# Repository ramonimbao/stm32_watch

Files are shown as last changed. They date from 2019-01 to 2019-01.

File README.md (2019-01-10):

# DIY STM32-based Watch

This repository contains the necessary files for building your own STM32-based watch.

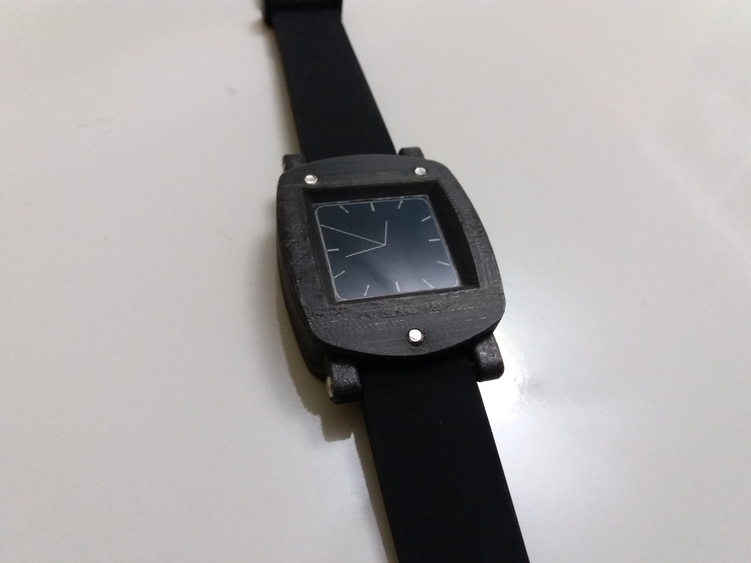
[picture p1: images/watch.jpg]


# Prerequisites

- [OpenOCD](https://gnu-mcu-eclipse.github.io/openocd/install/)
- [System Workbend for STM32](http://www.st.com/en/development-tools/sw4stm32.html)

# Assembly instructions

Details assembly instructions for the project are located in [BUILDING.md](BUILDING.md).

# License

This project is licensed under the MIT license - see the [LICENSE.md](LICENSE.md) for more details.

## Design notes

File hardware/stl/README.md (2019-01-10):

# Printing Settings

- 0.025 mm layer height
- 100% infill
- Supports enabled for [`back_face.stl`](back_face.stl) and [`lcd_support.stl`](lcd_support.stl).

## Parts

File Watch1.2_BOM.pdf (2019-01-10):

Watch v1.2 - Bill of Materials
Part | Value | Package | Description | Qty | Distributor | Order Number
C1,C5,C6,C7,C8, C12,C13,C14 | 100n | 0805 | CAP 100n, 0805 | 8 | MOUSER | 80-C0805C104K9R
C2,C3,C9 | 1u | 0805 | CAP 1u, 0805 | 3 | MOUSER | 603-CC0805KR5BB105
C4 | 4.7u | 0805 | CAP 4.7u, 0805 | 1 | MOUSER | 77-VJ0805G475KXYTBC
C10,C11 | 10p | 0805 | CAP, 10p, 0805 | 2 | MOUSER | 710-885012007010
D1 | LED | 0805 | LED, any, 0805 | 1 | MOUSER | 604-APT2012SGC
L1 | 1k | 0805 | FERRITE, 1k, 0805 | 1 | MOUSER | 963-BK2125HS102-T
P1 | | FPC-10-0.5 | 10-pin, 0.5mm-pitch FPC connector | 1 | MOUSER | 538-505110-1092
PB1,PB2,PB3 | | 4.46x3.5x3.3 | Tact switch | 3 | MOUSER | 688-SKRTLA
R1,R2,R3,R4 | 10k | 0805 | R, 10k, 0805 | 4 | MOUSER | 588-AS08J1002ET
R6 | 510 | 0805 | R, 510, 0805 | 1 | MOUSER | 71-CRCW0805510RJNEA
SB1,SB2,SB3 | 0 | 0805 | R, 0, 0805 | 3 | MOUSER | 667-ERJ-6GEY0R00V
U1 | STM32L051K8T6 | LQFP-32 | STM32L0 MCU | 1 | MOUSER | 511-STM32L051K8T6
U2 | | | Keystone 3003 | 1 | MOUSER | 534-3003
X1 | 32.768kHz | 3.2x1.5 | 3.2x1.5 32.768kHz 10ppm 7pF | 1 | MOUSER | 815-S07AIG-32.76871T
| LS013B7DH03 | | 1.28” Sharp Memory LCD | 1 | MOUSER | 852-LS013B7DH03

MISC PARTS
QTY
3 | M3x12 countersunk screws
2 | M3x8 countersunk screws
4 | M2x12 pan head screws
1 | 20mm watch strap
| 3D printed parts

## https://github.com/ramonimbao/stm32_watch/

blob/master/BUILDING.md (https://github.com/ramonimbao/stm32_watch/blob/master/BUILDING.md)

PART | DETAILED ASSEMBLY INSTRUCTIONS

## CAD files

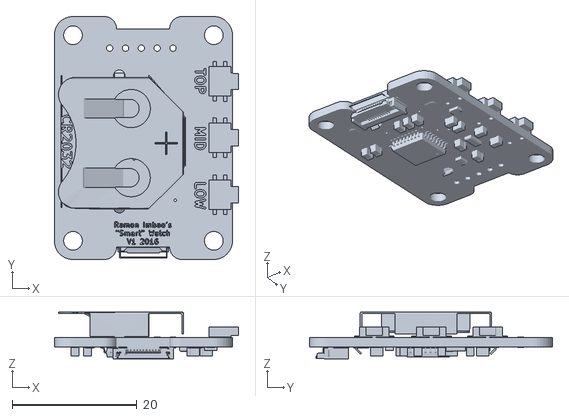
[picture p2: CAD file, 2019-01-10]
hardware/board/Export/Watch.stl
29.6 x 39.0 x 7.53

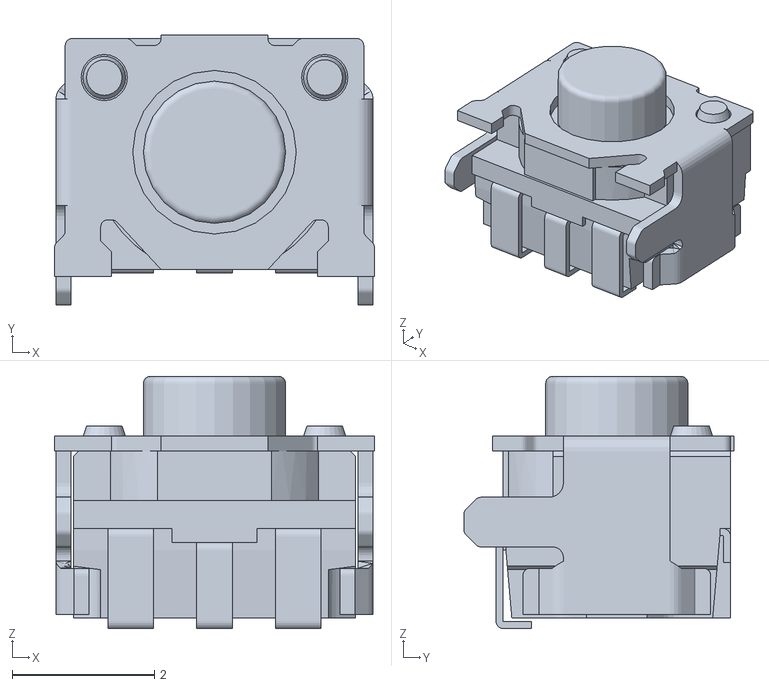
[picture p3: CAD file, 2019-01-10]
hardware/board/shapes3D/Tact_Switch_ALPS_SKRTLA.stl
4.50 x 3.80 x 3.55

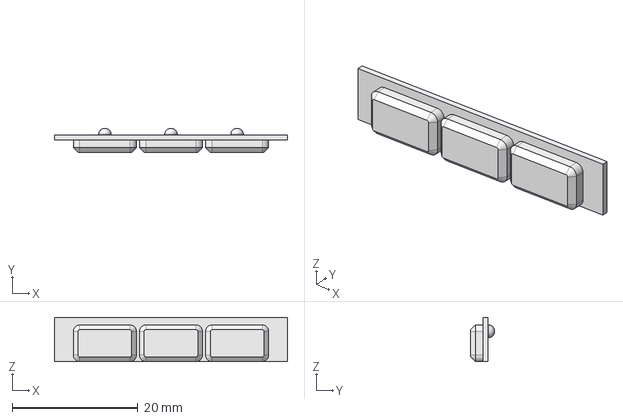
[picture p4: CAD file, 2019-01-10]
hardware/freecad/buttons_v2.fcstd
37.0 x 3.80 x 7.00 mm

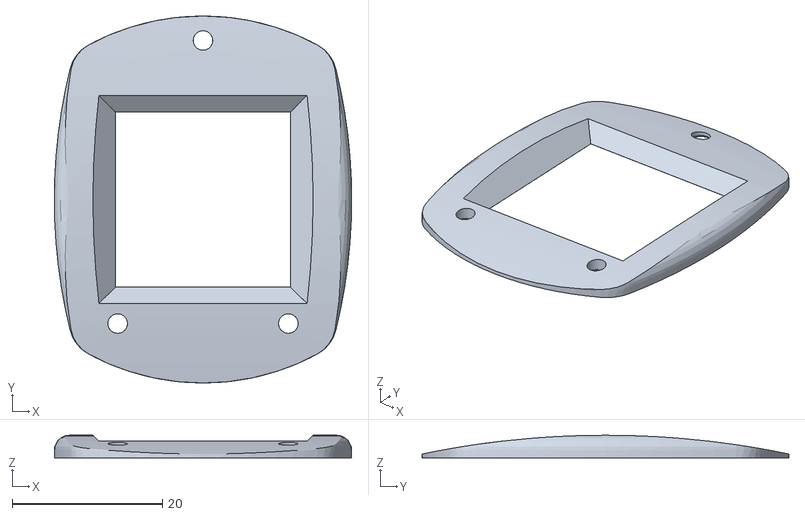
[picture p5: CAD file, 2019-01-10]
hardware/stl/watch_face.stl
39.6 x 48.8 x 3.00

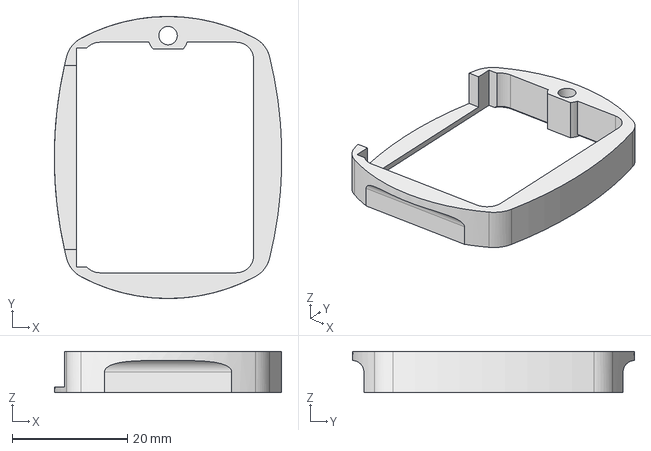
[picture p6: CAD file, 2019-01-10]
hardware/freecad/body_inner_v6.fcstd
39.5 x 48.9 x 7.20 mm

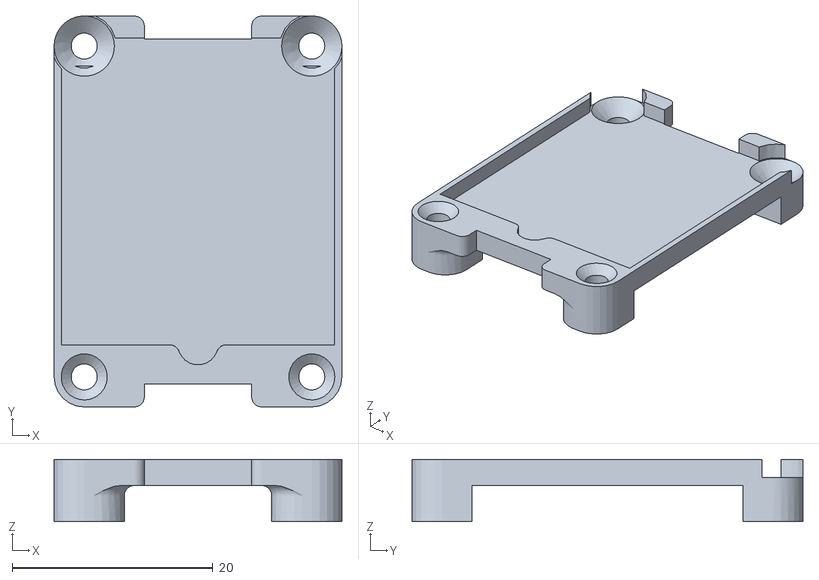
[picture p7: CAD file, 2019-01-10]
hardware/stl/lcd_support.stl
28.7 x 39.0 x 6.20

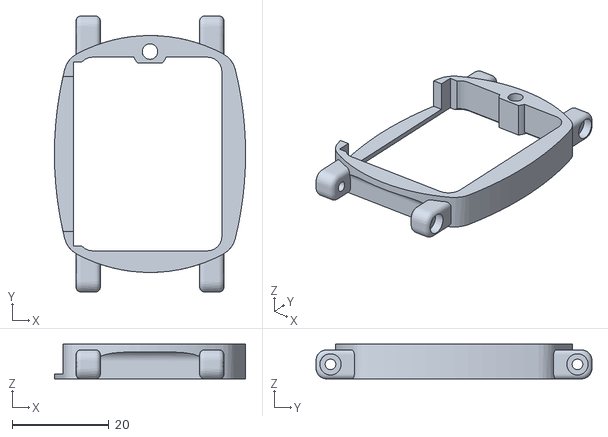
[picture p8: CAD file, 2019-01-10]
hardware/stl/body_inner.stl
39.5 x 57.0 x 7.20

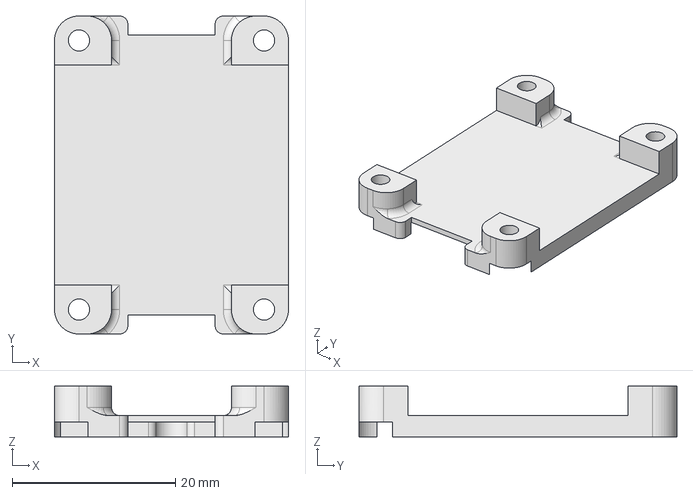
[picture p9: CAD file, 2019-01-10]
hardware/freecad/lcd_support_v4.fcstd
28.7 x 39.0 x 6.20 mm

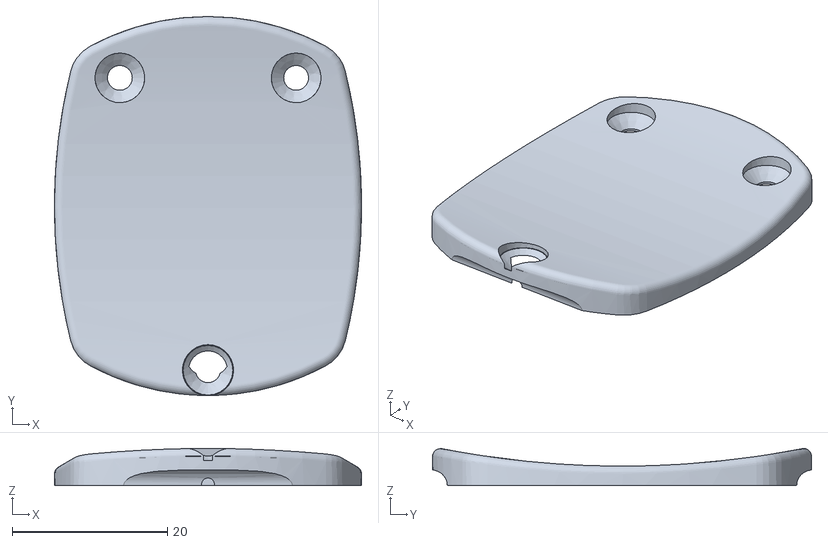
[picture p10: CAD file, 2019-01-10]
hardware/stl/back_face.stl
39.6 x 48.8 x 4.78

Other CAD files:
hardware/freecad/watch_face_v2.fcstd
hardware/stl/buttons.stl
hardware/board/Watch.stl

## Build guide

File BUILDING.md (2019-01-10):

# Assembly Instructions

Below, I detail how to properly assemble the watch from bare board to finished product.

## Tools used

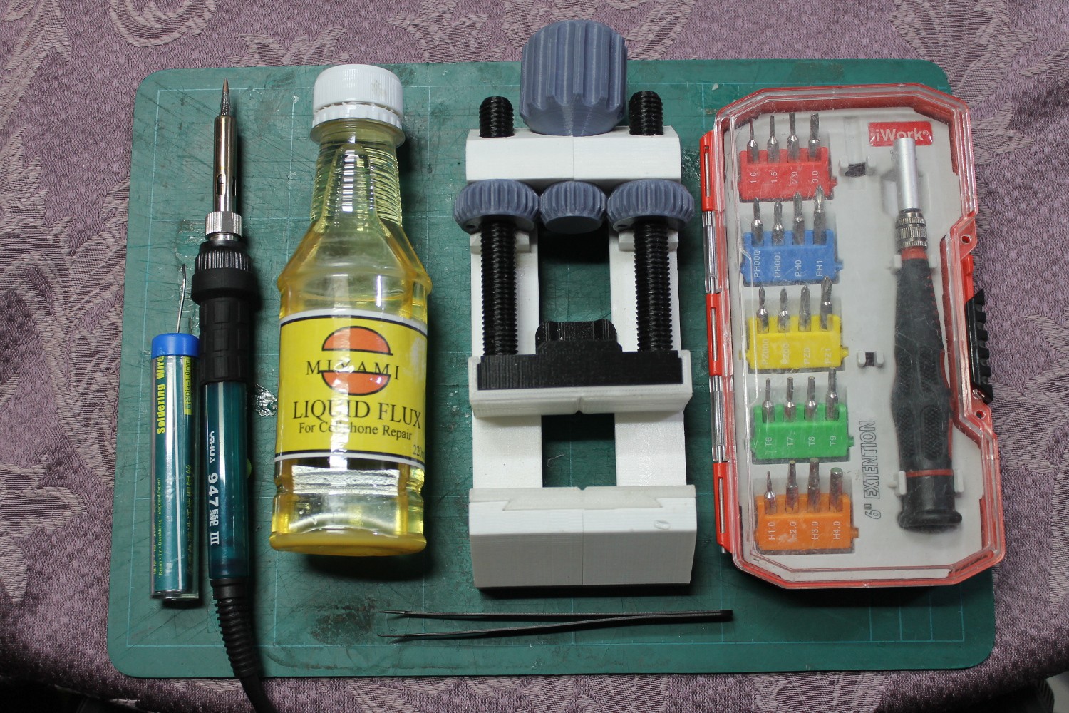
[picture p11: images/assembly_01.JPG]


- Soldering iron and lead (thinner is better)
- Liquid flux (pictured above is an el cheapo flux)
- SMD tweezers
- [PCB vise](https://www.thingiverse.com/thing:2064269) (since I don't own helping hands)
- Screwdriver set
- Solder wick (not pictured)

Have the bill of materials handy to easily identify which parts go where!

## Bare board

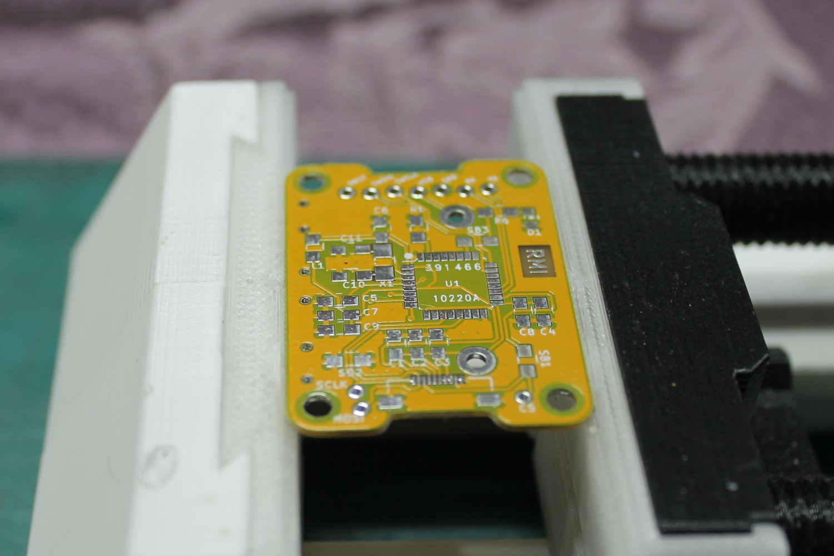
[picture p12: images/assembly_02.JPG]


Firstly, we'll work on the top part of the board. Specifically, the first thing I like soldering would be the FPC connector — it's the most difficult part to solder with a 0.5 mm pitch.

## FPC connector

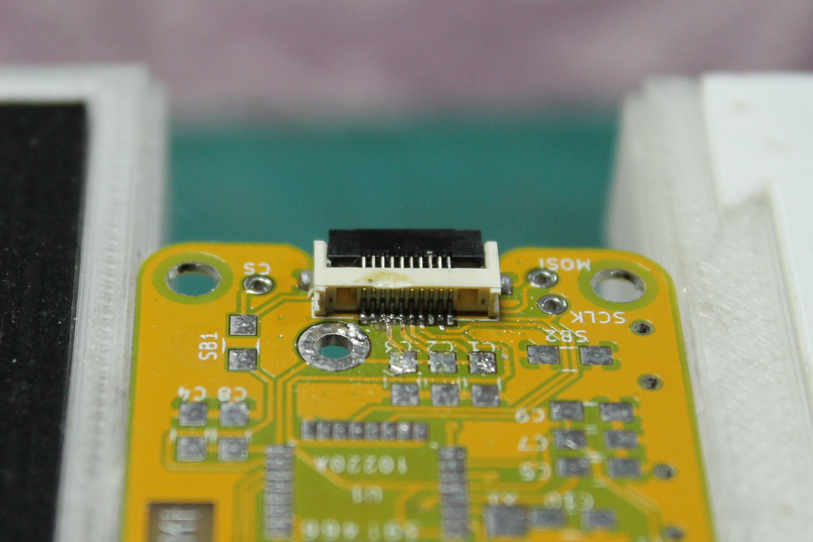
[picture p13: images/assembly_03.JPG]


Use plenty of flux and a solder wick to wick away any excess solder. Let's say pin 1 is the leftmost pin (though it's not). Don't worry about shorting pins 1 and 2, or pins 3, 4, 5, and 6. Those are GND and VBAT respectively. The rest of the pins must be isolated from each other however.

## Passives

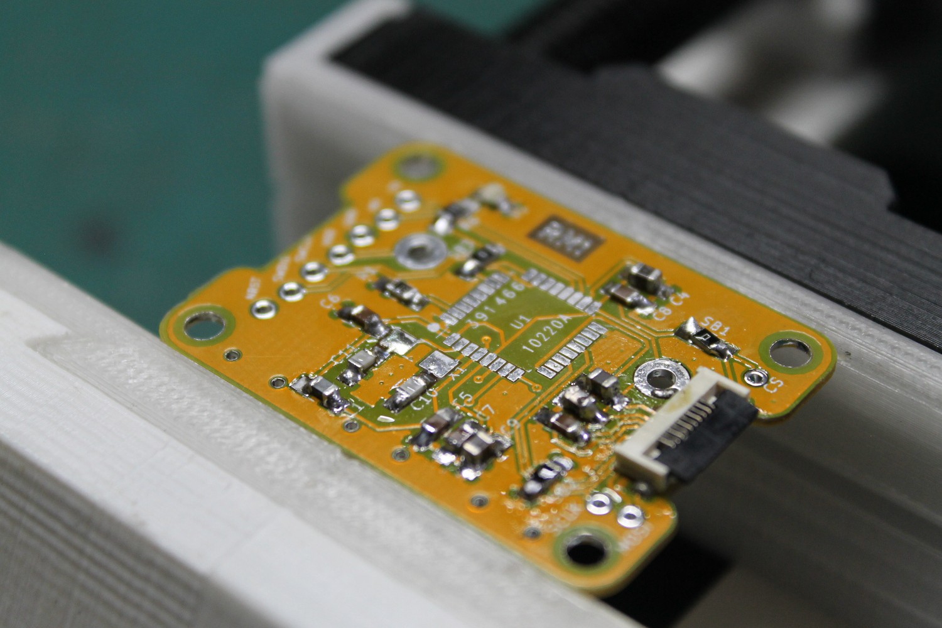
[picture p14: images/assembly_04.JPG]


Solder all the passives on the top part of the board. Just go through the bill of materials and take your time. Make sure to do a better job than I did as seen in the photo.

## Crystal

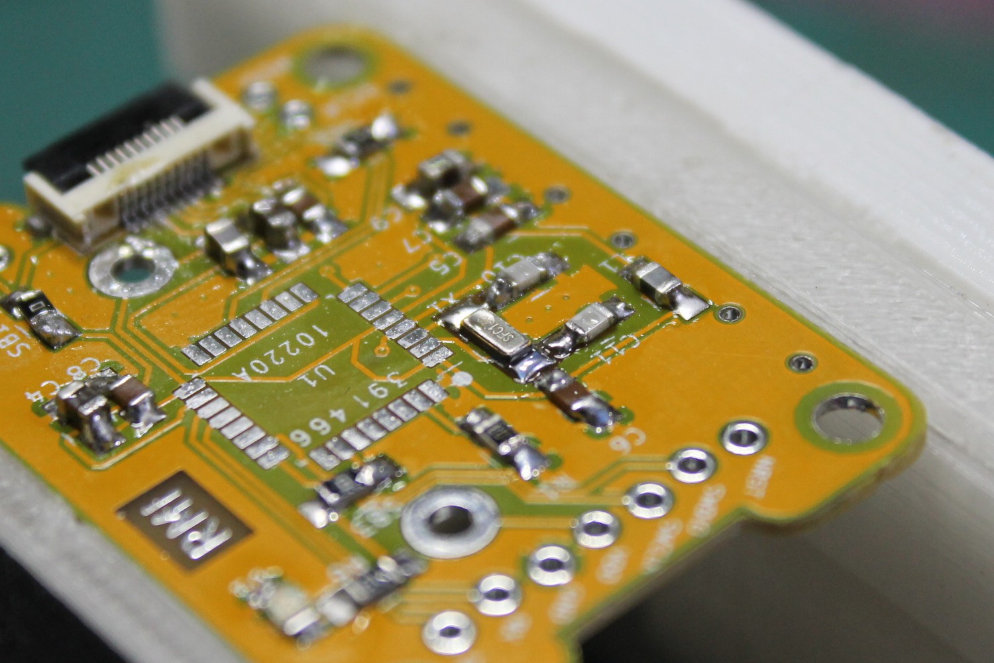
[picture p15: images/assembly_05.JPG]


I read somewhere that you shouldn't heat up the crystal too much or you'll damage it, so take care in soldering this.

## STM32 IC

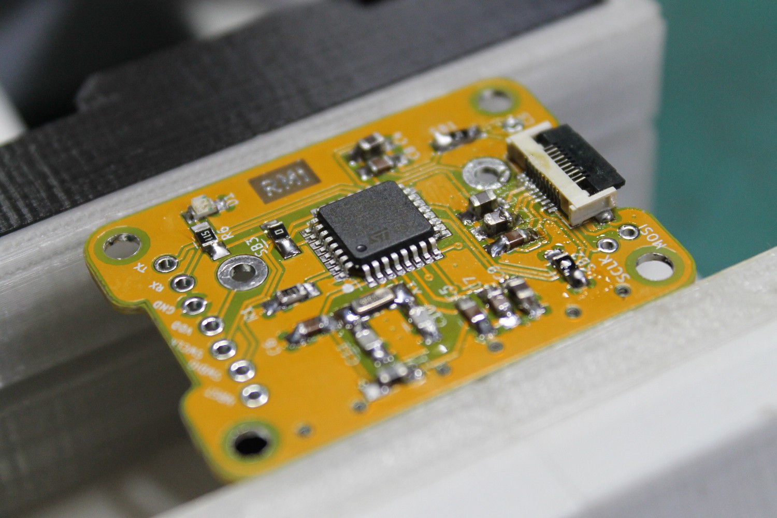
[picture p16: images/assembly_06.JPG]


Align the IC on all the pads. Make sure that the dot on the package matches the dot on the board indicated by the silkscreen.

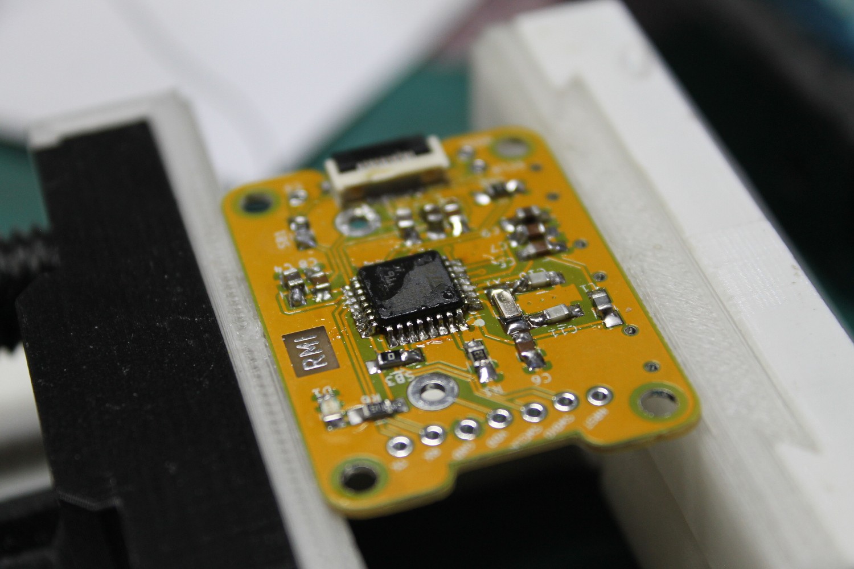
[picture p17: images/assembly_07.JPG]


Here it is all soldered up. As you can see, I was very liberal with the flux.

## Passives (back)

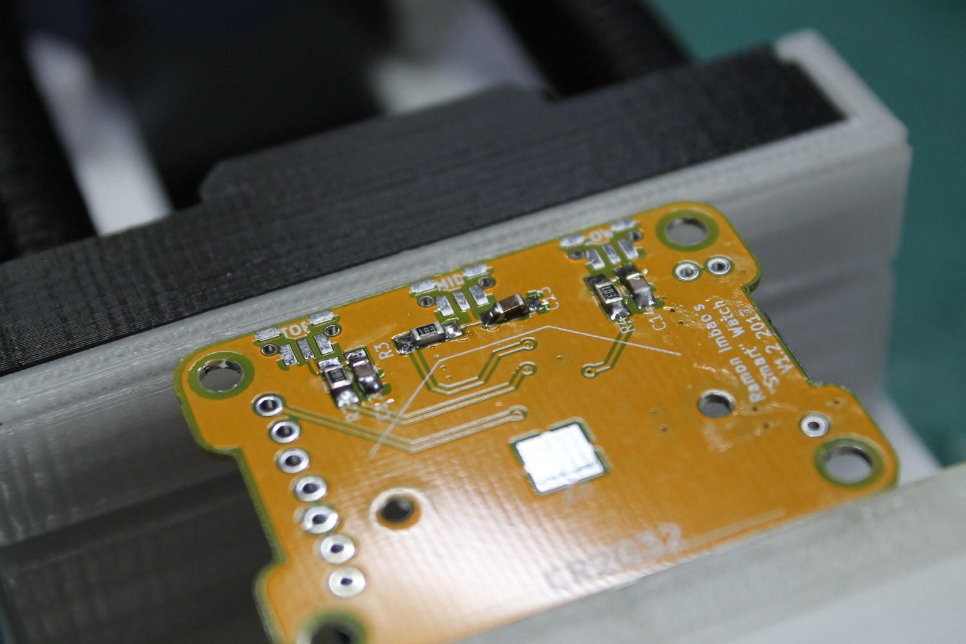
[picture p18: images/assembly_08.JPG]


Now you can flip the board and solder the rest of the passives at the back. All of these are just 100nF capacitors and 10kΩ resistors.

## Buttons

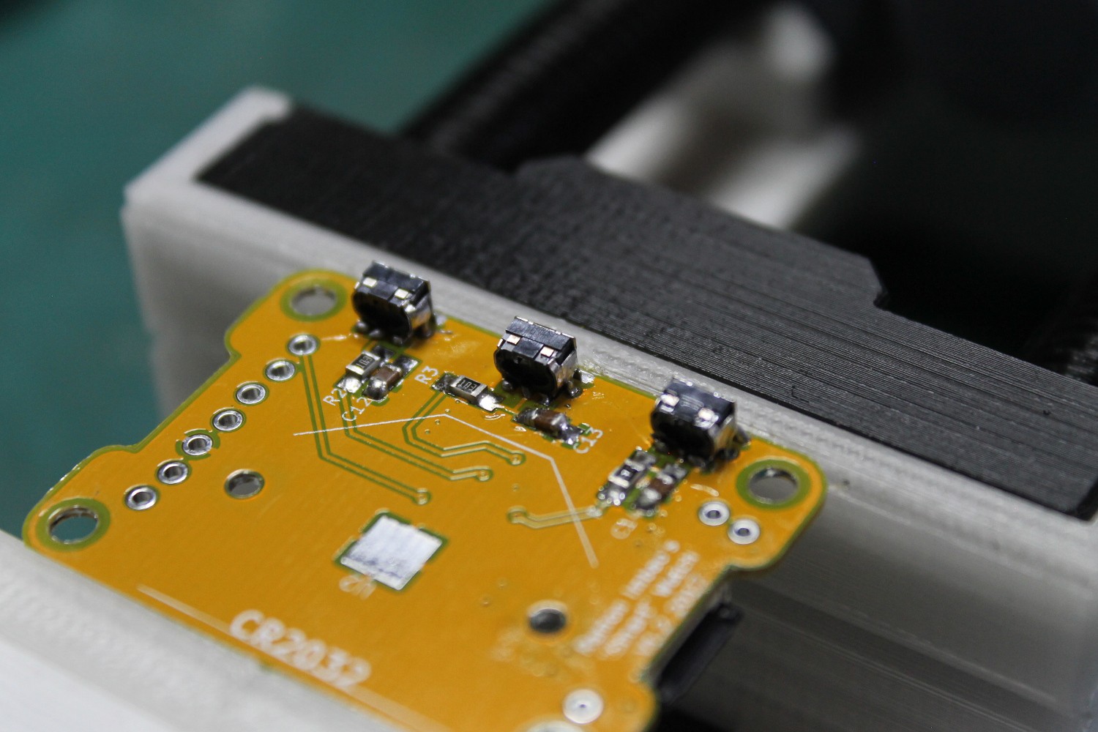
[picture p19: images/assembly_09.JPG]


Place the buttons and align them using the holes on the board. It's a bit more difficult to solder these since the leads don't extend outward. A hot air station might be better suited for this.

## Solder pad

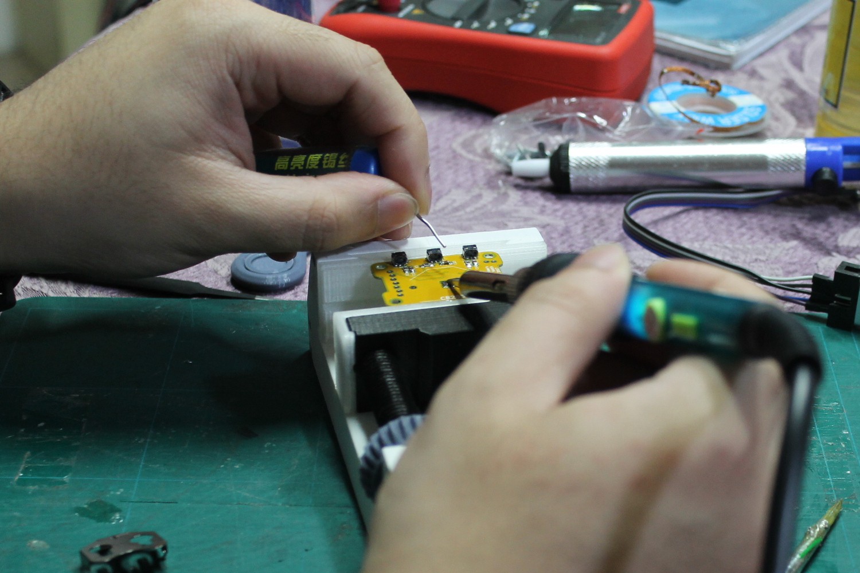
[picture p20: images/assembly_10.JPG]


Don't forget to add a *tiny* amount of solder to the big square pad you see. This helps create a tighter fit on the battery and ensures a good connection. This should create a small bump, around 1mm thick or less.

## Battery holder

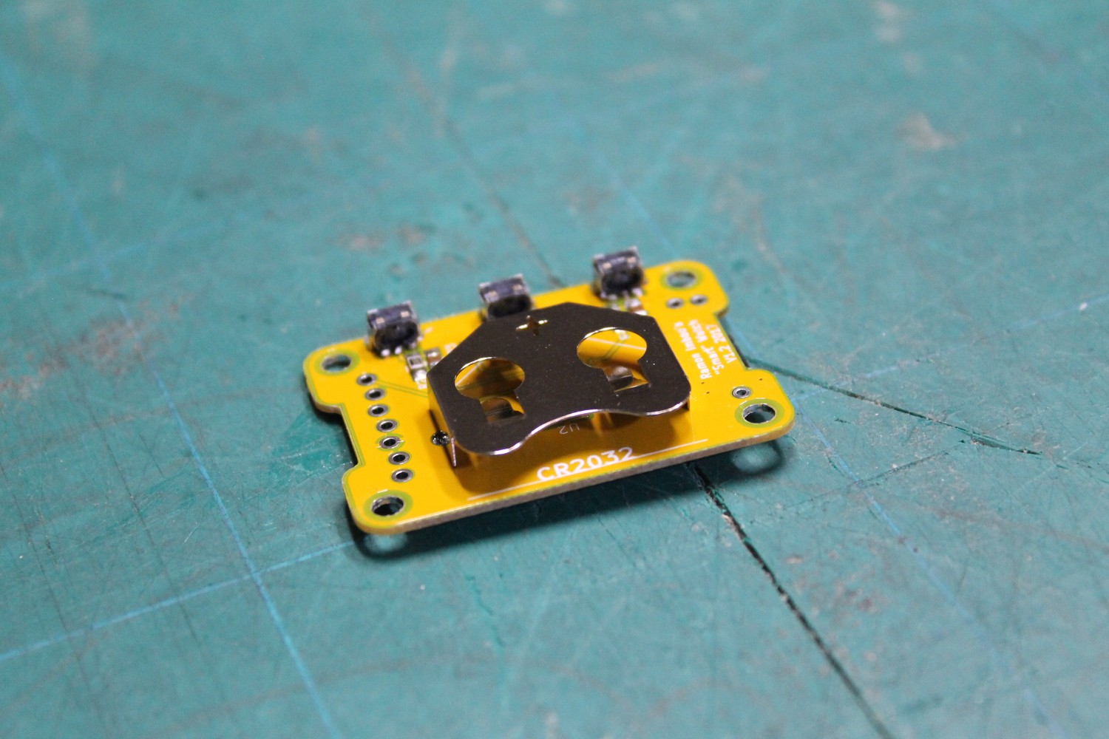
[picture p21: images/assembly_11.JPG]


Finally, solder the battery holder on. It's the only through-hole component of the build.

## Connect ST-Link

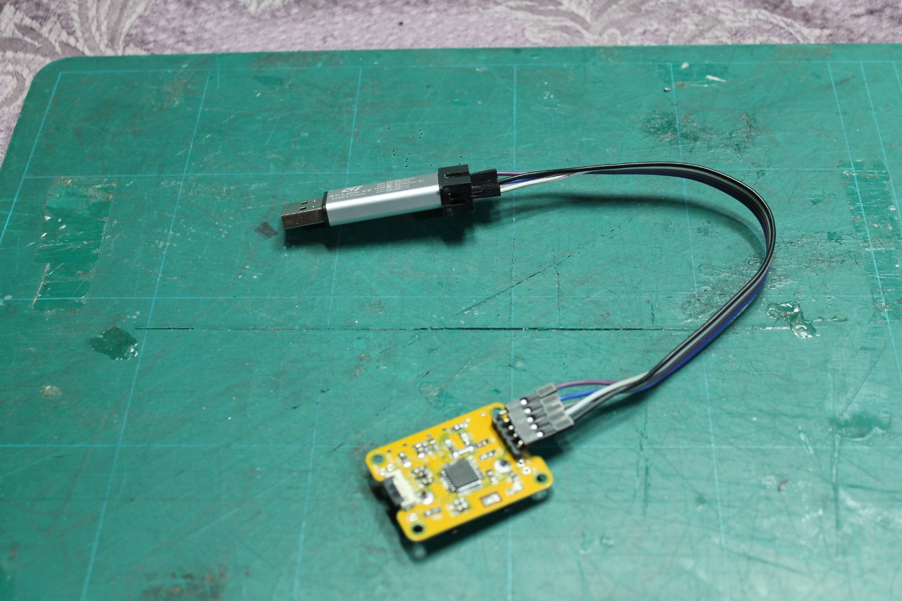
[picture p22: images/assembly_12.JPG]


I used a Chinese ST-Link clone. Simply connect the five relevant pins from the programmer to the board: `SWCLK`, `SWDIO`, `NRST`, `VCC`, and `GND`. There is no need to solder header pins to the board since it's staggered to ensure a tight fit.

## OpenOCD

Follow the necessary instructions for [installing OpenOCD on your system](https://gnu-mcu-eclipse.github.io/openocd/install/).

Open up a command line interface, and type in the following command to start up the OpenOCD debugger:

```
openocd -f interface/stlink-v2.cfg -f target/stm32l0.cfg
```

The output should be something like this:

```
Open On-Chip Debugger 0.10.0-dev-00399-g19df456 (2016-11-04-15:40)
Licensed under GNU GPL v2
For bug reports, read
	http://openocd.org/doc/doxygen/bugs.html
Info : auto-selecting first available session transport "hla_swd". To override use 'transport select <transport>'.
adapter speed: 300 kHz
adapter_nsrst_delay: 100
Info : The selected transport took over low-level target control. The results might differ compared to plain JTAG/SWD
none separate
Info : Unable to match requested speed 300 kHz, using 240 kHz
Info : Unable to match requested speed 300 kHz, using 240 kHz
Info : clock speed 240 kHz
Info : STLINK v2 JTAG v27 API v2 SWIM v6 VID 0x0483 PID 0x3748
Info : using stlink api v2
Info : Target voltage: 3.216787
Info : stm32l0.cpu: hardware has 4 breakpoints, 2 watchpoints
```

## Programming with SW4STM32

As my firmware files rely on [System Workbench for STM32 (SW4STM32)](http://www.st.com/en/development-tools/sw4stm32.html), a copy of that is needed to be installed.

Load up the project in SW4STM32, and flash to the board by pressing hitting Run.

## Connect the screen

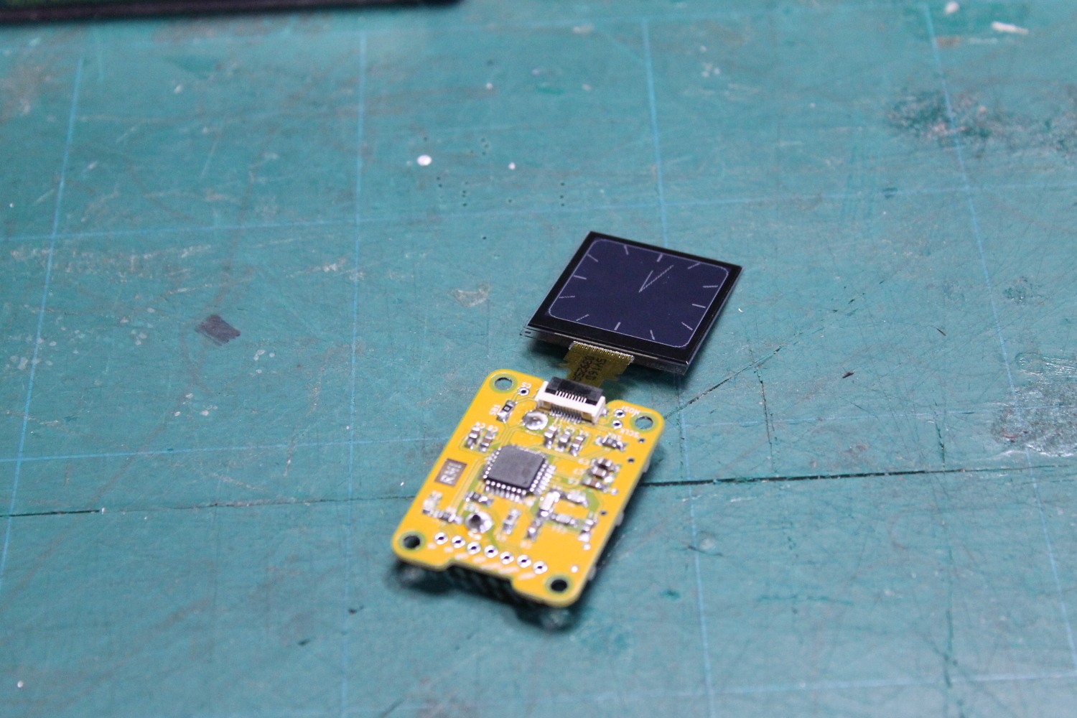
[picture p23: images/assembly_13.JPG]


Disconnect the programmer, connect a battery, and connect the screen via the 10-pin FPC connector. You should see the clock face on the display.

## Test buttons

The top and bottom buttons should move the minute hand forwards and backwards. The middle button should reset the second hand. The previous picture doesn't have a second hand, but a section of the code can be uncommented to have this appear.

## Attach screen support

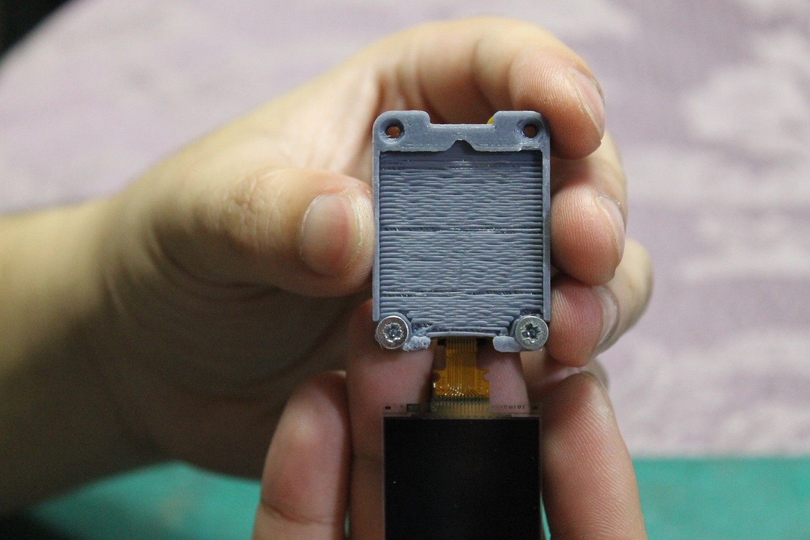
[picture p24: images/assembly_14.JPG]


It is **highly recommended** to pre-tap the holes on the screen support. You can use an M3 tap or just use a screw to create the threads.

Place the screen support on the board and partially screw in two M3×8 countersunk screws at the bottom. Take note of the orientation of the 3D printed part in relation to the screen.

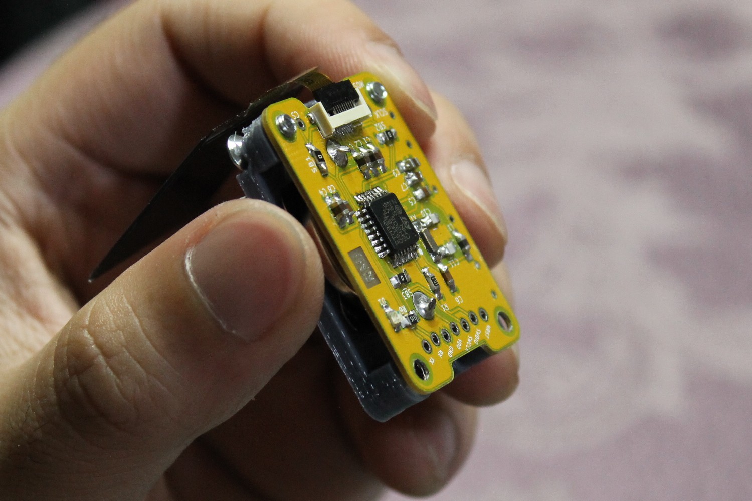
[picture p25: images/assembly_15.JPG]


The screws should stick out by around 2-3mm so you can use it to align it to the back piece.

## Back piece

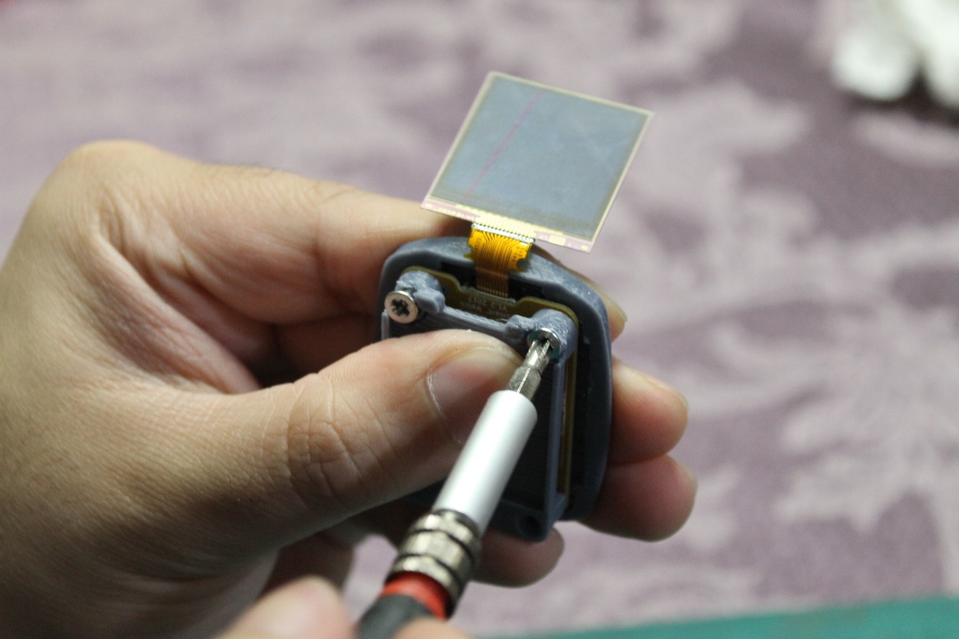
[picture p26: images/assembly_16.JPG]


Here the board and screen support is being screwed into the back piece. The threaded sections on the back piece are quite short so make sure you accidentally enlarge the hole. Tighten the screws until the top of them is flush with the screen support.

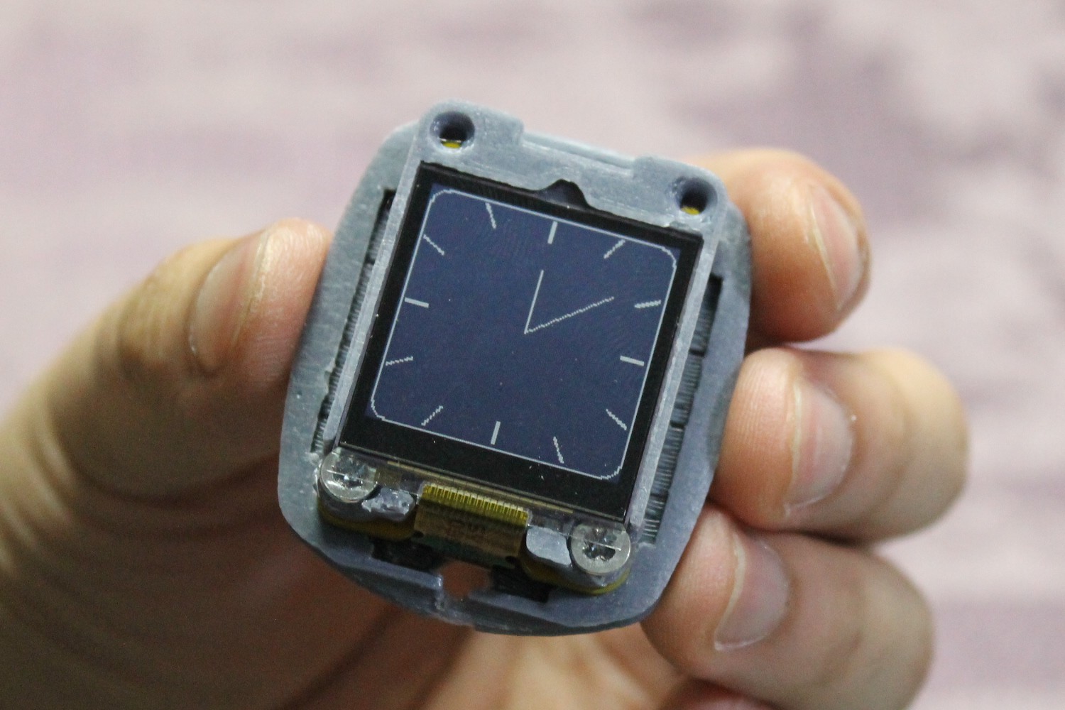
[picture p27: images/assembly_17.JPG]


The screen should be able to sit flush on the screen support. Be careful not to bend or shatter the LCD when inserting — these things are incredibly fragile!

## Middle piece and flexible buttons

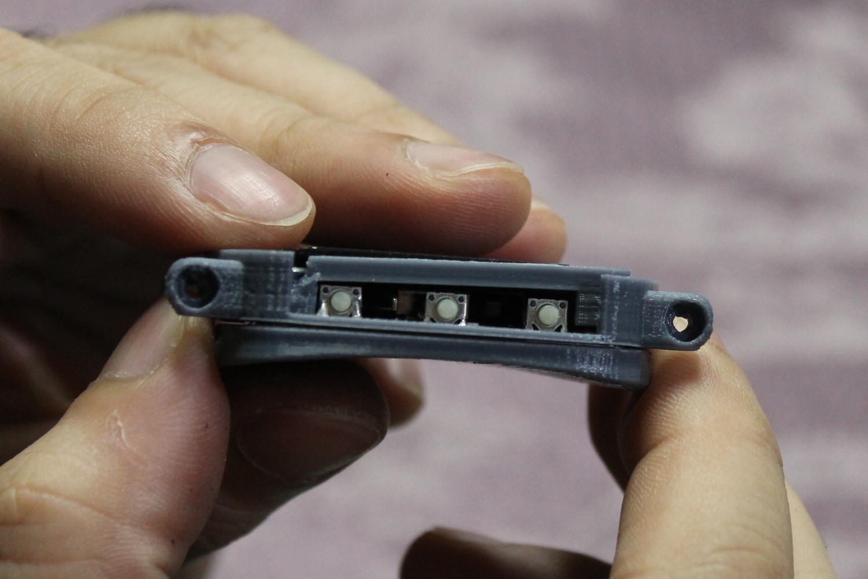
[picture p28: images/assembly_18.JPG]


Now you can insert the middle piece through the assembly. Take note that the cutout faces the side with the buttons, and that the thinner section is nearer to the bottom.

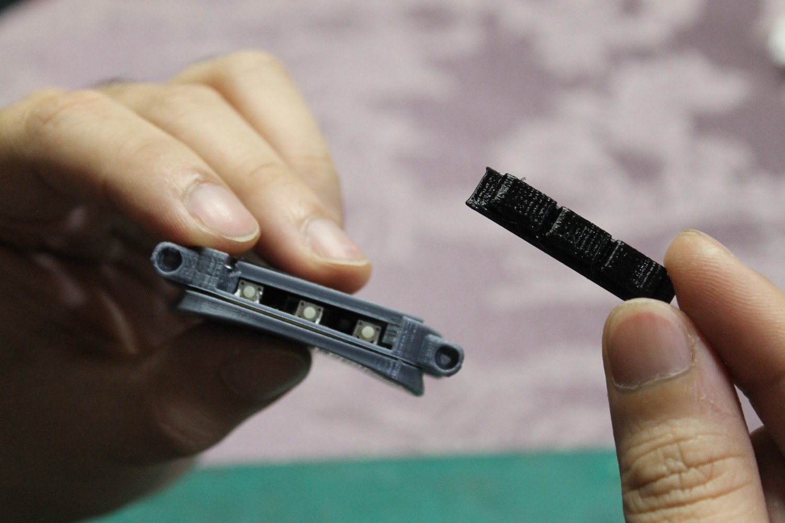
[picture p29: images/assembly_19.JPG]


Now place the flexible buttons inside. The buttons go flush side top.

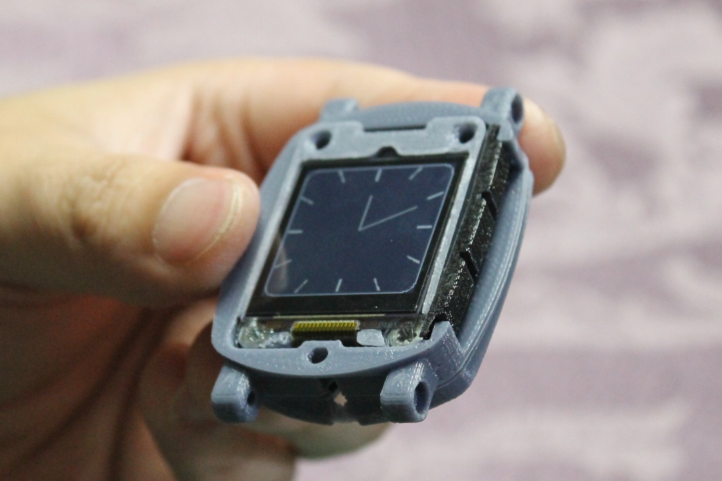
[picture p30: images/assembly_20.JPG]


## Fit cover and screw from back

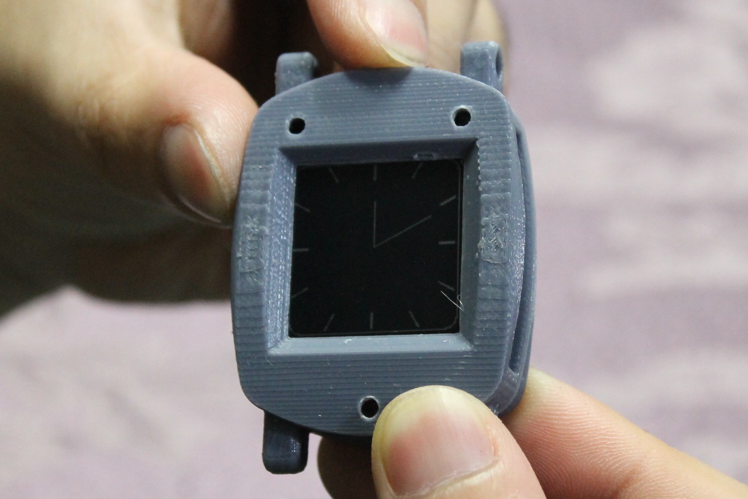
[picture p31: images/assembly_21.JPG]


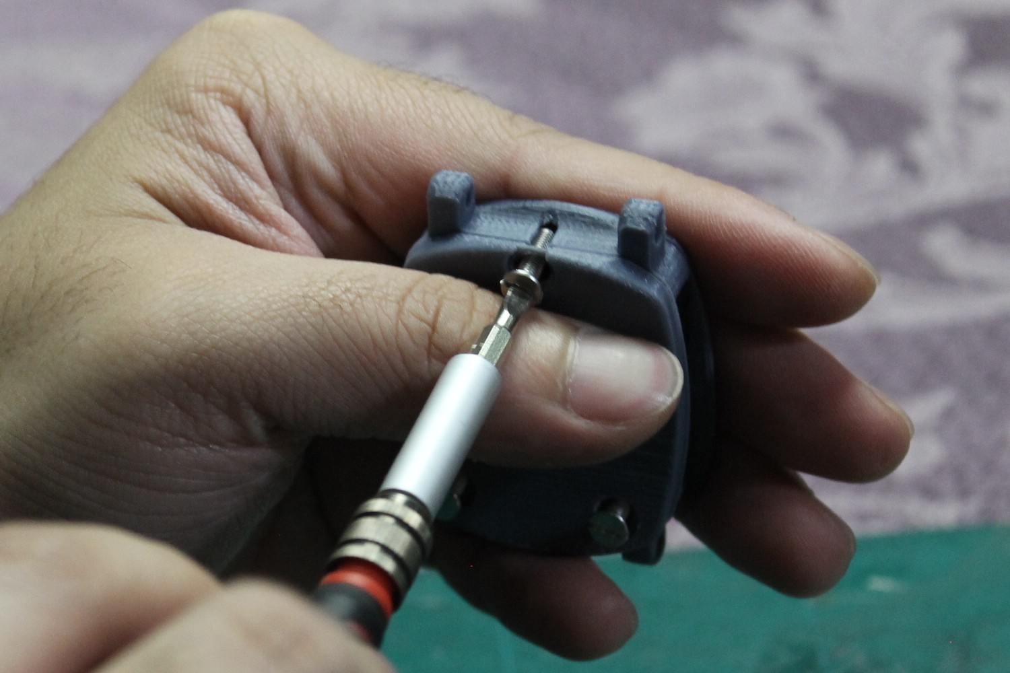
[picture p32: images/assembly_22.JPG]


Place the cover in front and insert the M3×12 countersunk screws from the back. This may be tight if you don't tap the threads of the screen support beforehand.

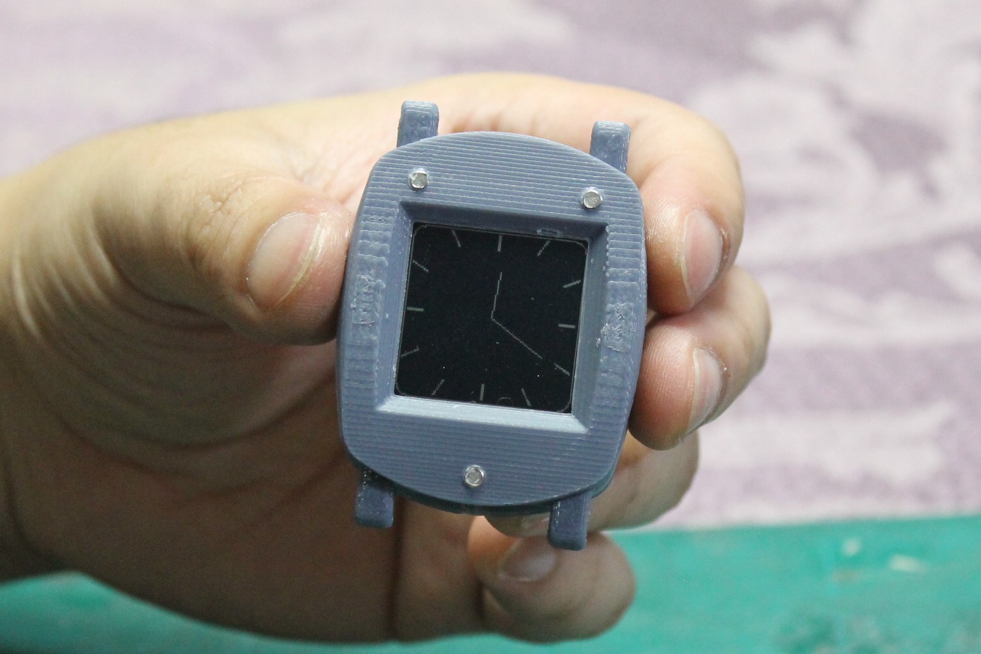
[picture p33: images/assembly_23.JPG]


Almost complete. Yes, the screws stick out somewhat, but it's not bothersome for me.

## Attach straps

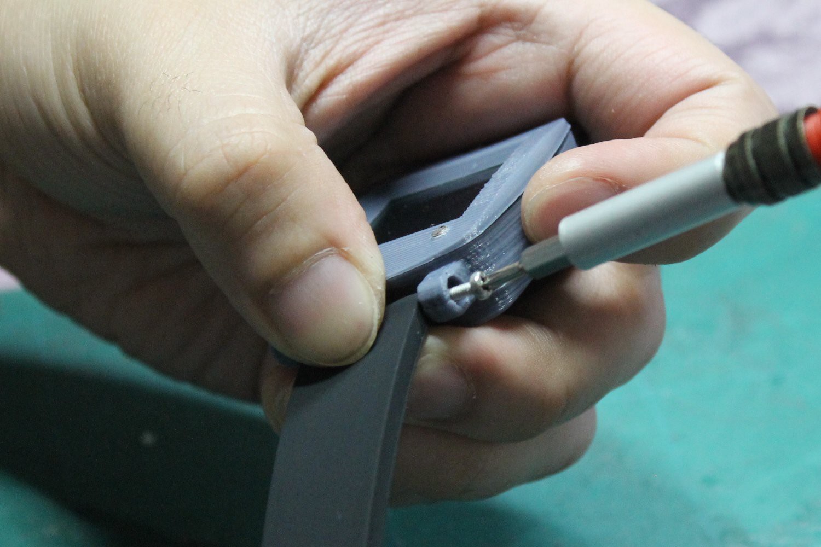
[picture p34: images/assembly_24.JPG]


Use the M2×12 cap head screws to attach the straps to the body. There are four in total.

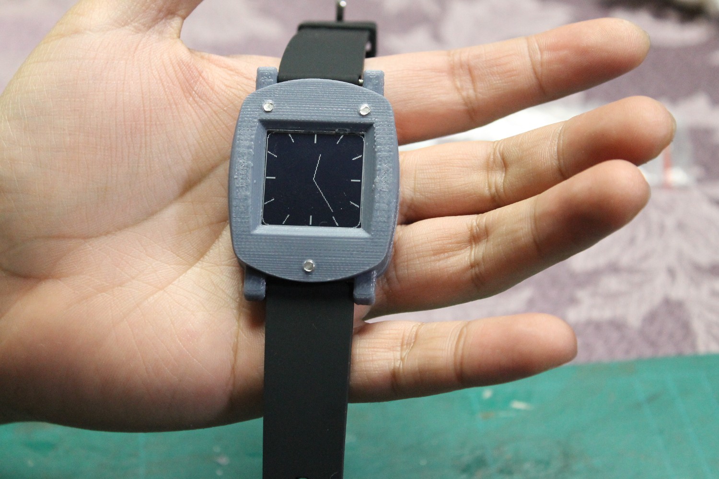
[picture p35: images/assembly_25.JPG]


**Complete!** Wear it with pride. Make more for your family and friends.

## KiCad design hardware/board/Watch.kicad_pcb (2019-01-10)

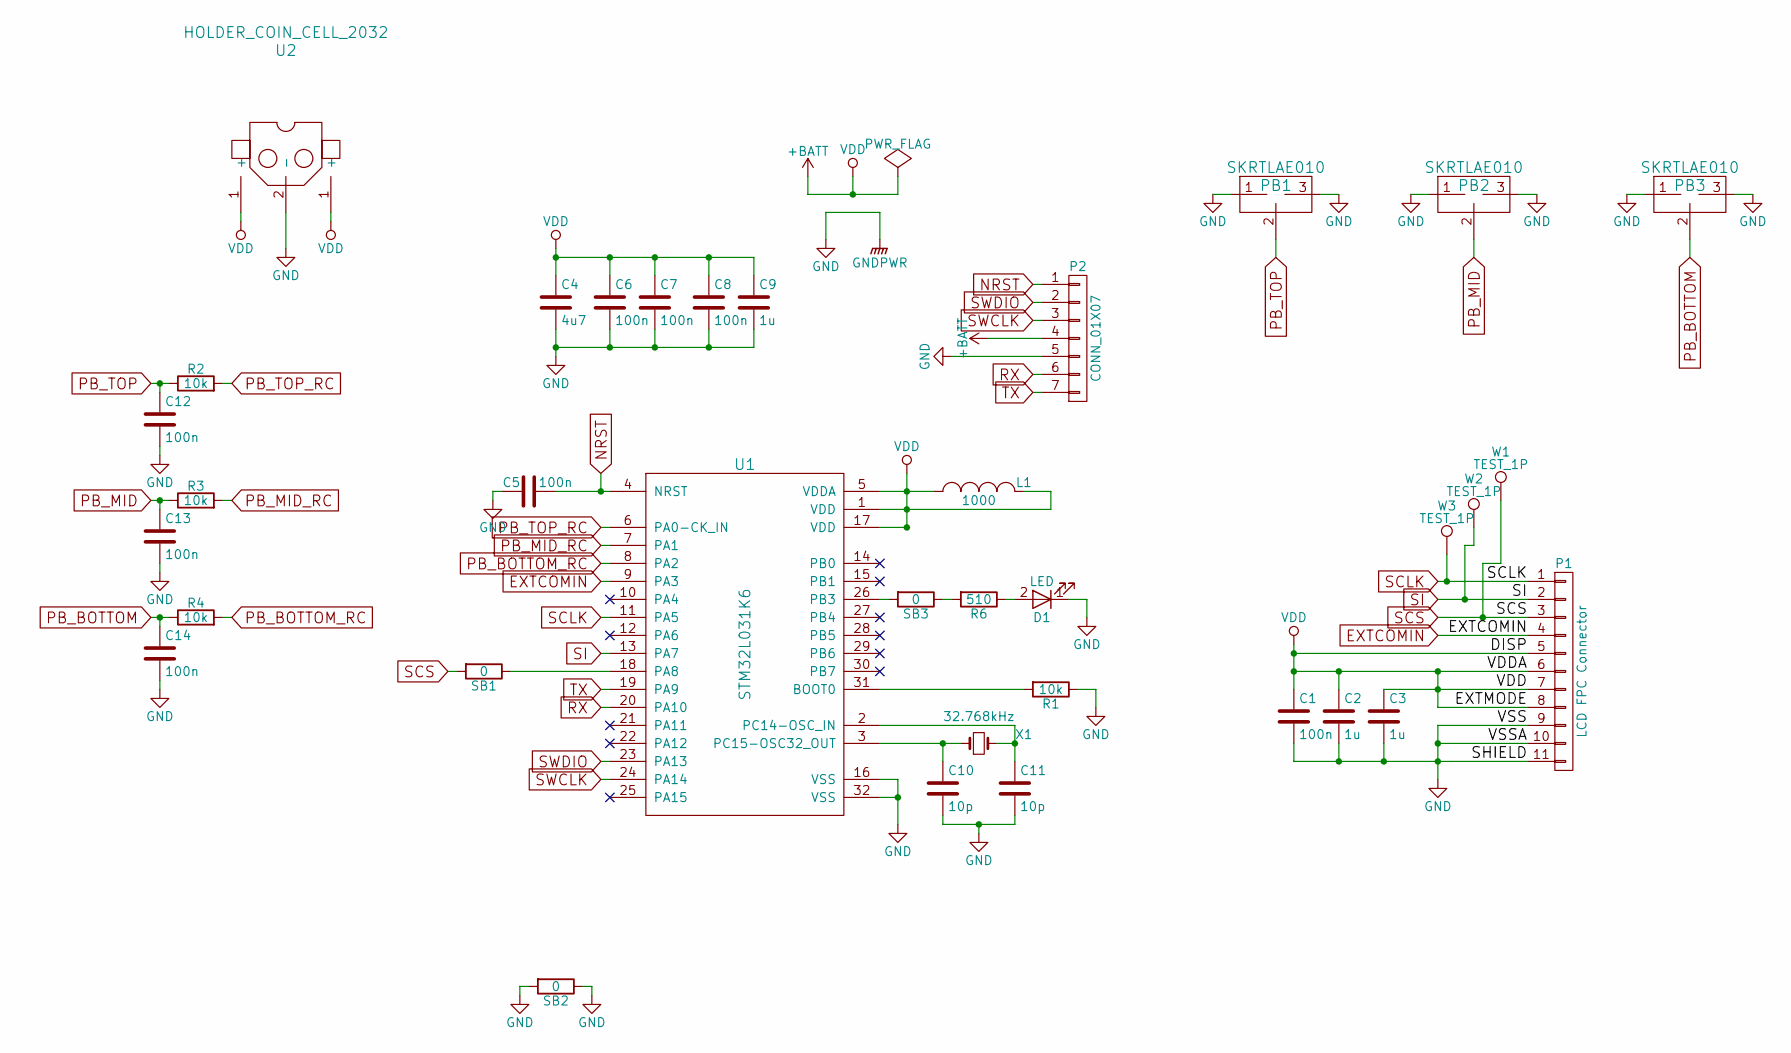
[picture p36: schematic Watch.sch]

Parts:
C1, C5, C6, C7, C8, C12, C13, C14: 100n; C_0805_HandSoldering
C2, C3, C9: 1u; C_0805_HandSoldering
C4: 4u7; C_0805_HandSoldering
C10, C11: 10p; C_0805_HandSoldering
D1: LED; LED_0805
L1: 1000; R_0805_HandSoldering
P1: LCD FPC Connector; FPC_10pin_0.5pitch
P2: CONN_01X07; Pin_Header_Straight_1x07_Pitch2.54mm
PB1, PB2, PB3: SKRTLAE010; SKTDLDE010
R1, R2, R3, R4: 10k; R_0805_HandSoldering
R6: 510; R_0805_HandSoldering
SB1, SB2, SB3: 0; R_0805_HandSoldering
U1: STM32L031K6; LQFP-32_7x7mm_Pitch0.8mm
U2: HOLDER_COIN_CELL_2032; HOLDER_COIN_CELL_2032_THROUGHHOLE
W1, W2, W3: TEST_1P; Measurement_Point_Round-TH_Small
X1: 32.768kHz; Crystal_3.2x1.5mm_HandSoldering

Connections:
+BATT: C1.1, C2.1, C3.1, C4.1, C6.1, C7.1, C8.1, C9.1, L1.1, L1.2, P1.5, P1.6, P1.7, P1.8, P2.4, U1.1 (VDD), U1.5 (VDDA), U1.17 (VDD), U2.1 (+)
EXTCOMIN: P1.4, U1.9 (PA3)
GND: C1.2, C2.2, C3.2, C4.2, C5.2, C6.2, C7.2, C8.2, C9.2, C10.2, C11.2, C12.2, C13.2, C14.2, D1.1 (K), P1.9, P1.10, P1.11, P2.5, PB1.1, PB1.3, PB2.1, PB2.3, PB3.1, PB3.3, R1.1, SB2.1, SB2.2, U1.16 (VSS), U1.32 (VSS), U2.2 (-)
NRST: C5.1, P2.1, U1.4 (NRST)
unnamed: C10.1, U1.3 (PC15-OSC32_OUT), X1.1
unnamed: C11.1, U1.2 (PC14-OSC_IN), X1.2
unnamed: D1.2 (A), R6.1
unnamed: R1.2, U1.31 (BOOT0)
unnamed: R6.2, SB3.1
unnamed: SB1.1, U1.18 (PA8)
unnamed: SB3.2, U1.26 (PB3)
PB_BOTTOM: C14.1, PB3.2, R4.1
PB_BOTTOM_RC: R4.2, U1.8 (PA2)
PB_MID: C13.1, PB2.2, R3.1
PB_MID_RC: R3.2, U1.7 (PA1)
PB_TOP: C12.1, PB1.2, R2.1
PB_TOP_RC: R2.2, U1.6 (PA0-CK_IN)
RX: P2.6, U1.20 (PA10)
SCLK: P1.1, U1.11 (PA5), W3.1
SCS: P1.3, SB1.2, W1.1
SI: P1.2, U1.13 (PA7), W2.1
SWCLK: P2.3, U1.24 (PA14)
SWDIO: P2.2, U1.23 (PA13)
TX: P2.7, U1.19 (PA9)

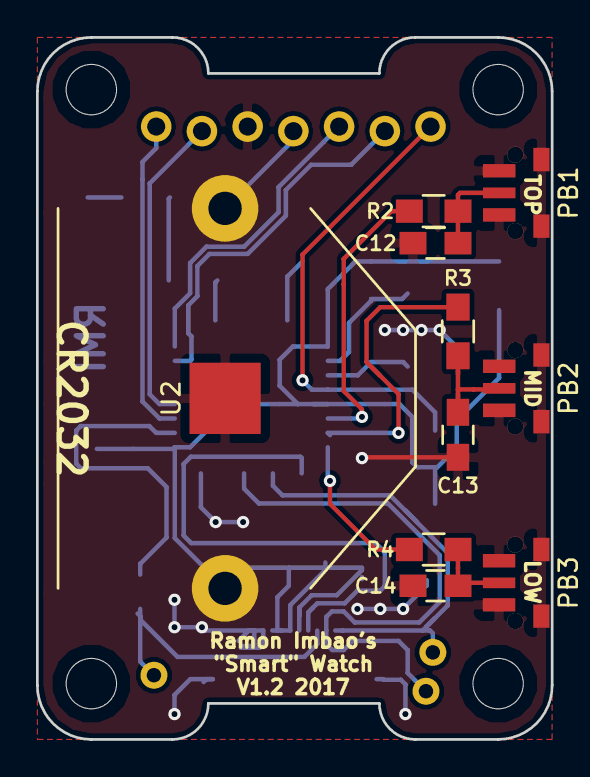
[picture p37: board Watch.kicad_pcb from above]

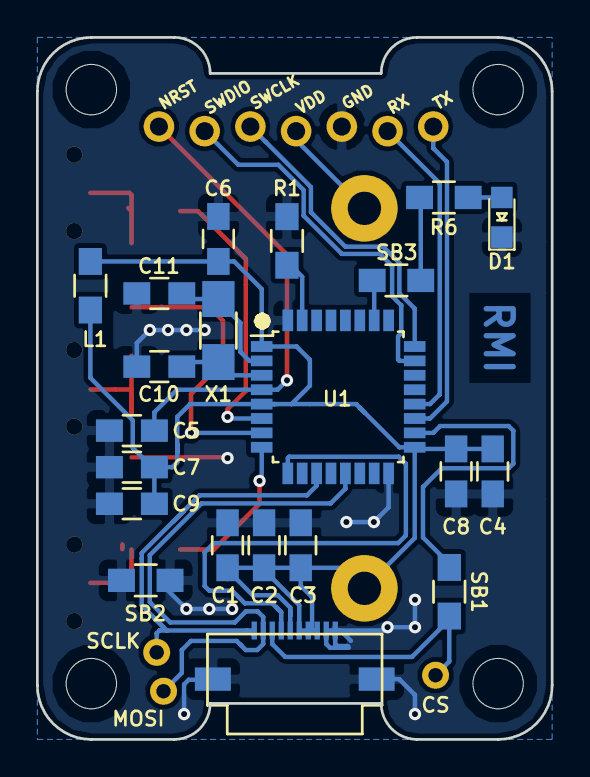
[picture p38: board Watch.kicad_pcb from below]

Board: 2 copper layers, 28.6 x 39.0 mm, 35 parts (25 on the bottom side), 24 nets.

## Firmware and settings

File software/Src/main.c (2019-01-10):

/**
  ******************************************************************************
  * File Name          : main.c
  * Description        : Main program body
  ******************************************************************************
  *
  * Copyright (c) 2017 STMicroelectronics International N.V. 
  * All rights reserved.
  *
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
  ******************************************************************************
  */
/* Includes ------------------------------------------------------------------*/
#include "main.h"
#include "stm32l0xx_hal.h"
#include "cmsis_os.h"

/* USER CODE BEGIN Includes */
#include "inittriglut.h"
#include <stdlib.h>
/* USER CODE END Includes */

RTC_HandleTypeDef hrtc;

SPI_HandleTypeDef hspi1;
DMA_HandleTypeDef hdma_spi1_tx;

osThreadId defaultTaskHandle;

/* USER CODE BEGIN PV */
#define SCREEN_WIDTH	128
#define SCREEN_HEIGHT	128

volatile uint8_t data[SCREEN_HEIGHT * ((SCREEN_WIDTH >> 3) + 2)];
const uint8_t command[1] = {0x03};
const uint8_t clear_cmd[2] = {0x05, 0x00};

RTC_TimeTypeDef sTimeStamp;
RTC_DateTypeDef sDateStamp;
HAL_RTCStateTypeDef currentState;

uint8_t hours = 12, minutes = 01, seconds = 30;

typedef enum {
	false = 0U,
	true = 1U
} bool;

typedef void (*drawFuncDef)(uint8_t, uint8_t);
/* USER CODE END PV */

void SystemClock_Config(void);
void Error_Handler(void);
static void MX_GPIO_Init(void);
static void MX_DMA_Init(void);
static void MX_SPI1_Init(void);
static void MX_RTC_Init(void);
void StartDefaultTask(void const * argument);

/* USER CODE BEGIN PFP */

/* USER CODE END PFP */

/* USER CODE BEGIN 0 */
static void setPixel(uint8_t x, uint8_t y) {
	if (x > 127 || y > 127) return;
	/*x %= 128;
	y %= 128;*/
	data[(y*((SCREEN_WIDTH>>3)+2))+(x>>3)+1] &= ~(1 << (x % 8));
}

static void clearPixel(uint8_t x, uint8_t y) {
	if (x > 127 || y > 127) return;
	/*x %= 128;
	y %= 128;*/
	data[(y*((SCREEN_WIDTH>>3)+2))+(x>>3)+1] |= (1 << (x % 8));
}

void clearDisplay() {
	for(uint8_t dy=0; dy<SCREEN_HEIGHT; dy++) {
		for(uint8_t dx=0; dx<SCREEN_WIDTH; dx++) {
			setPixel(dx,dy);
		}
	}
}

static drawFuncDef otherFunction(const drawFuncDef func) {
	if (func == setPixel) return clearPixel;
	else return setPixel;
}

static void drawCircle(uint8_t x0, uint8_t y0, uint8_t radius, const drawFuncDef drawFunc) {
	int x = radius;
	int y = 0;
	int err = 0;
	while (x >= y) {
		drawFunc(x0 + x, y0 + y);
		drawFunc(x0 + y, y0 + x);
		drawFunc(x0 - y, y0 + x);
		drawFunc(x0 - x, y0 + y);
		drawFunc(x0 - x, y0 - y);
		drawFunc(x0 - y, y0 - x);
		drawFunc(x0 + y, y0 - x);
		drawFunc(x0 + x, y0 - y);

		y += 1;
		err += 1 + (y << 2);
		if (((err-x) << 2) + 1 > 0) {
			x -= 1;
			err += 1 - (x << 2);
		}
	}
}

// source: https://rosettacode.org/wiki/Bitmap/Bresenham%27s_line_algorithm#C
static void drawLine(uint8_t x0, uint8_t y0, uint8_t x1, uint8_t y1, const drawFuncDef drawFunc) {
	int dx = abs(x1-x0), sx = x0 < x1 ? 1 : -1;
	int dy = abs(y1-y0), sy = y0 < y1 ? 1 : -1;
	int err = (dx > dy ? dx : -dy)/2, e2;

	for (;;) {
		drawFunc(x0,y0);
		if (x0==x1 && y0==y1) break;
		e2 = err;
		if (e2 > -dx)	{ err -= dy; x0 += sx; }
		if (e2 < dy)	{ err += dx; y0 += sy; }
	}
}

static void drawRect(uint8_t x1, uint8_t y1, uint8_t w, uint8_t h, const drawFuncDef drawFunc) {
	drawLine(x1,y1,x1+w,y1,drawFunc);
	drawLine(x1,y1,x1,y1+h,drawFunc);
	drawLine(x1,y1+h,x1+w,y1+h,drawFunc);
	drawLine(x1+w,y1,x1+w,y1+h,drawFunc);
}

static void drawArc(uint8_t x0, uint8_t y0, uint8_t radius, int16_t start, int16_t end, const drawFuncDef drawFunc) {
	for(int16_t theta=start+1; theta<end; theta++) {
		int32_t _x1 = x0 + radius * i16_cos(theta-1) / 32768;
		int32_t _y1 = y0 + radius * i16_sin(theta-1) / 32768;
		int32_t _x2 = x0 + radius * i16_cos(theta) / 32768;
		int32_t _y2 = y0 + radius * i16_sin(theta) / 32768;
		//drawFunc((uint8_t)_x, (uint8_t)_y);
		drawLine(_x1, _y1, _x2, _y2, drawFunc);
	}
}

static void drawRoundedRect(uint8_t x1, uint8_t y1, uint8_t w, uint8_t h, uint8_t r, const drawFuncDef drawFunc) {
	drawLine(x1+r,y1,x1+w-r,y1,drawFunc);
	drawLine(x1,y1+r,x1,y1+h-r,drawFunc);
	drawLine(x1+r,y1+h,x1+w-r,y1+h,drawFunc);
	drawLine(x1+w,y1+r,x1+w,y1+h-r,drawFunc);

	drawArc(x1+r,y1+r,r,180,270,drawFunc);
	drawArc(x1+w-r,y1+r,r,-90,0,drawFunc);
	drawArc(x1+r,y1+h-r,r,90,180,drawFunc);
	drawArc(x1+w-r,y1+h-r,r,0,90,drawFunc);
}
/*
static void drawChar8(uint8_t x, uint8_t y, char c, bool bg, const drawFuncDef drawFunc) {
	uint16_t n = c - ' ';
	drawFuncDef other = otherFunction(drawFunc);

	for (uint8_t i=0; i<16; i++) {
		for(uint8_t j=0; j<8; j++) {
			if  ((font8x16[(n*16)+i] >> (7-j)) & 0x01) {
				setPixel((x+j)%SCREEN_WIDTH, (y+i)%SCREEN_HEIGHT);
			}
			else {
				if (bg) other((x+j)%SCREEN_WIDTH, (y+i)%SCREEN_HEIGHT);
			}
		}
	}
}

static void drawChar32(uint8_t x, uint8_t y, char c, bool bg, const drawFuncDef drawFunc) {
	uint16_t n = c - '0';
	drawFuncDef other = otherFunction(drawFunc);
	if (n > 10) n = 11;

	for(uint8_t i=0; i<29; i++) {
		for(uint8_t j=0; j<24; j++) {
			if ((font24x29[(n*29)+i] >> (23-j)) & (uint32_t)0x01) {
				drawFunc((x+j)%SCREEN_WIDTH, (y+i)%SCREEN_HEIGHT);
			}
			else {
				if (bg) other((x+j)%SCREEN_WIDTH, (y+i)%SCREEN_HEIGHT);
			}
		}
	}
}

static void drawStr8(uint8_t x, uint8_t y, char str[], bool bg, const drawFuncDef drawFunc) {
	char *c = NULL;
	uint8_t x0 = x;
	for(c = str; *c != '\0'; c++) {
		if (*c == '\n') {
			y += 16;
			x = x0;
		}
		else {
			drawChar8(x, y, *c, bg, drawFunc);
			x += 8;
		}
	}
}

static void drawStr24(uint8_t x, uint8_t y, char str[], bool bg, const drawFuncDef drawFunc) {
	char *c = NULL;
	for(c = str; *c != '\0'; c++) {
		drawChar32(x, y, *c, bg, drawFunc);
		x += 24;
	}
}*/
/* USER CODE END 0 */

int main(void)
{

  /* USER CODE BEGIN 1 */
	for(uint8_t i=0; i<SCREEN_HEIGHT; i++) {
			data[i*((SCREEN_WIDTH >> 3)+2)] = i+1;
			data[(i+1)*((SCREEN_WIDTH>>3)+2)-1] = 0x00;
		}
  /* USER CODE END 1 */

  /* MCU Configuration----------------------------------------------------------*/

  /* Reset of all peripherals, Initializes the Flash interface and the Systick. */
  HAL_Init();

  /* Configure the system clock */
  SystemClock_Config();

  /* Initialize all configured peripherals */
  MX_GPIO_Init();
  MX_DMA_Init();
  MX_SPI1_Init();
  MX_RTC_Init();

  /* USER CODE BEGIN 2 */
  HAL_SuspendTick();
  HAL_PWREx_EnableLowPowerRunMode();

  updateDisplay();
  /* USER CODE END 2 */

  /* USER CODE BEGIN RTOS_MUTEX */
  /* add mutexes, ... */
  /* USER CODE END RTOS_MUTEX */

  /* USER CODE BEGIN RTOS_SEMAPHORES */
  /* add semaphores, ... */
  /* USER CODE END RTOS_SEMAPHORES */

  /* USER CODE BEGIN RTOS_TIMERS */
  /* start timers, add new ones, ... */
  /* USER CODE END RTOS_TIMERS */

  /* Create the thread(s) */
  /* definition and creation of defaultTask */
  /*osThreadDef(defaultTask, StartDefaultTask, osPriorityNormal, 0, 128);
  defaultTaskHandle = osThreadCreate(osThread(defaultTask), NULL);*/

  /* USER CODE BEGIN RTOS_THREADS */
  /* add threads, ... */
  /* USER CODE END RTOS_THREADS */

  /* USER CODE BEGIN RTOS_QUEUES */
  /* add queues, ... */
  /* USER CODE END RTOS_QUEUES */
 

  /* Start scheduler */
  osKernelStart();
  
  /* We should never get here as control is now taken by the scheduler */

  /* Infinite loop */
  /* USER CODE BEGIN WHILE */
  while (1)
  {
  /* USER CODE END WHILE */

  /* USER CODE BEGIN 3 */

  }
  /* USER CODE END 3 */

}

/** System Clock Configuration
*/
void SystemClock_Config(void)
{

  RCC_OscInitTypeDef RCC_OscInitStruct;
  RCC_ClkInitTypeDef RCC_ClkInitStruct;
  RCC_PeriphCLKInitTypeDef PeriphClkInit;

    /**Configure the main internal regulator output voltage 
    */
  __HAL_PWR_VOLTAGESCALING_CONFIG(PWR_REGULATOR_VOLTAGE_SCALE2);

    /**Initializes the CPU, AHB and APB busses clocks 
    */
  RCC_OscInitStruct.OscillatorType = RCC_OSCILLATORTYPE_LSE|RCC_OSCILLATORTYPE_MSI;
  RCC_OscInitStruct.LSEState = RCC_LSE_ON;
  RCC_OscInitStruct.MSIState = RCC_MSI_ON;
  RCC_OscInitStruct.MSICalibrationValue = 0;
  RCC_OscInitStruct.MSIClockRange = RCC_MSIRANGE_5;
  RCC_OscInitStruct.PLL.PLLState = RCC_PLL_NONE;
  if (HAL_RCC_OscConfig(&RCC_OscInitStruct) != HAL_OK)
  {
    Error_Handler();
  }

    /**Initializes the CPU, AHB and APB busses clocks 
    */
  RCC_ClkInitStruct.ClockType = RCC_CLOCKTYPE_HCLK|RCC_CLOCKTYPE_SYSCLK
                              |RCC_CLOCKTYPE_PCLK1|RCC_CLOCKTYPE_PCLK2;
  RCC_ClkInitStruct.SYSCLKSource = RCC_SYSCLKSOURCE_MSI;
  RCC_ClkInitStruct.AHBCLKDivider = RCC_SYSCLK_DIV1;
  RCC_ClkInitStruct.APB1CLKDivider = RCC_HCLK_DIV1;
  RCC_ClkInitStruct.APB2CLKDivider = RCC_HCLK_DIV1;

  if (HAL_RCC_ClockConfig(&RCC_ClkInitStruct, FLASH_LATENCY_0) != HAL_OK)
  {
    Error_Handler();
  }

  PeriphClkInit.PeriphClockSelection = RCC_PERIPHCLK_RTC;
  PeriphClkInit.RTCClockSelection = RCC_RTCCLKSOURCE_LSE;
  if (HAL_RCCEx_PeriphCLKConfig(&PeriphClkInit) != HAL_OK)
  {
    Error_Handler();
  }

    /**Configure LSE Drive Capability 
    */
  __HAL_RCC_LSEDRIVE_CONFIG(RCC_LSEDRIVE_LOW);

    /**Configure the Systick interrupt time 
    */
  HAL_SYSTICK_Config(HAL_RCC_GetHCLKFreq()/1000);

    /**Configure the Systick 
    */
  HAL_SYSTICK_CLKSourceConfig(SYSTICK_CLKSOURCE_HCLK);

  /* SysTick_IRQn interrupt configuration */
  HAL_NVIC_SetPriority(SysTick_IRQn, 3, 0);
}

/* RTC init function */
static void MX_RTC_Init(void)
{

  RTC_TimeTypeDef sTime;
  RTC_DateTypeDef sDate;

    /**Initialize RTC Only 
    */
  hrtc.Instance = RTC;
  hrtc.Init.HourFormat = RTC_HOURFORMAT_24;
  hrtc.Init.AsynchPrediv = 127;
  hrtc.Init.SynchPrediv = 255;
  hrtc.Init.OutPut = RTC_OUTPUT_DISABLE;
  hrtc.Init.OutPutRemap = RTC_OUTPUT_REMAP_NONE;
  hrtc.Init.OutPutPolarity = RTC_OUTPUT_POLARITY_HIGH;
  hrtc.Init.OutPutType = RTC_OUTPUT_TYPE_OPENDRAIN;
  if (HAL_RTC_Init(&hrtc) != HAL_OK)
  {
    Error_Handler();
  }

    /**Initialize RTC and set the Time and Date 
    */
  sTime.Hours = 0x0;
  sTime.Minutes = 0x0;
  sTime.Seconds = 0x0;
  sTime.DayLightSaving = RTC_DAYLIGHTSAVING_NONE;
  sTime.StoreOperation = RTC_STOREOPERATION_RESET;
  if (HAL_RTC_SetTime(&hrtc, &sTime, RTC_FORMAT_BCD) != HAL_OK)
  {
    Error_Handler();
  }

  sDate.WeekDay = RTC_WEEKDAY_MONDAY;
  sDate.Month = RTC_MONTH_JANUARY;
  sDate.Date = 0x1;
  sDate.Year = 0x0;

  if (HAL_RTC_SetDate(&hrtc, &sDate, RTC_FORMAT_BCD) != HAL_OK)
  {
    Error_Handler();
  }

    /**Enable the WakeUp 
    */
  if (HAL_RTCEx_SetWakeUpTimer_IT(&hrtc, 59, RTC_WAKEUPCLOCK_CK_SPRE_16BITS) != HAL_OK)
  {
    Error_Handler();
  }

}

/* SPI1 init function */
static void MX_SPI1_Init(void)
{

  hspi1.Instance = SPI1;
  hspi1.Init.Mode = SPI_MODE_MASTER;
  hspi1.Init.Direction = SPI_DIRECTION_2LINES;
  hspi1.Init.DataSize = SPI_DATASIZE_8BIT;
  hspi1.Init.CLKPolarity = SPI_POLARITY_LOW;
  hspi1.Init.CLKPhase = SPI_PHASE_1EDGE;
  hspi1.Init.NSS = SPI_NSS_SOFT;
  hspi1.Init.BaudRatePrescaler = SPI_BAUDRATEPRESCALER_2;
  hspi1.Init.FirstBit = SPI_FIRSTBIT_LSB;
  hspi1.Init.TIMode = SPI_TIMODE_DISABLE;
  hspi1.Init.CRCCalculation = SPI_CRCCALCULATION_DISABLE;
  hspi1.Init.CRCPolynomial = 7;
  if (HAL_SPI_Init(&hspi1) != HAL_OK)
  {
    Error_Handler();
  }

}

/** 
  * Enable DMA controller clock
  */
static void MX_DMA_Init(void) 
{
  /* DMA controller clock enable */
  __HAL_RCC_DMA1_CLK_ENABLE();

  /* DMA interrupt init */
  /* DMA1_Channel2_3_IRQn interrupt configuration */
  HAL_NVIC_SetPriority(DMA1_Channel2_3_IRQn, 3, 0);
  HAL_NVIC_EnableIRQ(DMA1_Channel2_3_IRQn);

}

/** Configure pins as 
        * Analog 
        * Input 
        * Output
        * EVENT_OUT
        * EXTI
*/
static void MX_GPIO_Init(void)
{

  GPIO_InitTypeDef GPIO_InitStruct;

  /* GPIO Ports Clock Enable */
  __HAL_RCC_GPIOC_CLK_ENABLE();
  __HAL_RCC_GPIOA_CLK_ENABLE();
  __HAL_RCC_GPIOB_CLK_ENABLE();

  /*Configure GPIO pin Output Level */
  HAL_GPIO_WritePin(GPIOA, EXTCOMIN_Pin|LCD_SCS_Pin, GPIO_PIN_RESET);

  /*Configure GPIO pin Output Level */
  HAL_GPIO_WritePin(LED_GPIO_Port, LED_Pin, GPIO_PIN_RESET);

  /*Configure GPIO pins : PB_TOP_Pin PB_MID_Pin PB_LOW_Pin */
  GPIO_InitStruct.Pin = PB_TOP_Pin|PB_MID_Pin|PB_LOW_Pin;
  GPIO_InitStruct.Mode = GPIO_MODE_IT_FALLING;
  GPIO_InitStruct.Pull = GPIO_PULLUP;
  HAL_GPIO_Init(GPIOA, &GPIO_InitStruct);

  /*Configure GPIO pins : EXTCOMIN_Pin LCD_SCS_Pin */
  GPIO_InitStruct.Pin = EXTCOMIN_Pin|LCD_SCS_Pin;
  GPIO_InitStruct.Mode = GPIO_MODE_OUTPUT_PP;
  GPIO_InitStruct.Pull = GPIO_PULLDOWN;
  GPIO_InitStruct.Speed = GPIO_SPEED_FREQ_LOW;
  HAL_GPIO_Init(GPIOA, &GPIO_InitStruct);

  /*Configure GPIO pin : LED_Pin */
  GPIO_InitStruct.Pin = LED_Pin;
  GPIO_InitStruct.Mode = GPIO_MODE_OUTPUT_PP;
  GPIO_InitStruct.Pull = GPIO_PULLDOWN;
  GPIO_InitStruct.Speed = GPIO_SPEED_FREQ_LOW;
  HAL_GPIO_Init(LED_GPIO_Port, &GPIO_InitStruct);

  /* EXTI interrupt init*/
  HAL_NVIC_SetPriority(EXTI0_1_IRQn, 3, 0);
  HAL_NVIC_EnableIRQ(EXTI0_1_IRQn);

  HAL_NVIC_SetPriority(EXTI2_3_IRQn, 3, 0);
  HAL_NVIC_EnableIRQ(EXTI2_3_IRQn);

}

/* USER CODE BEGIN 4 */
void vApplicationIdleHook(void) {
	HAL_PWR_EnterSLEEPMode(PWR_MAINREGULATOR_ON, PWR_SLEEPENTRY_WFE);
	//HAL_PWREx_EnableLowPowerRunMode()
	//HAL_PWREx_EnableUltraLowPower()
}

void updateDisplay() {
	clearDisplay();

		  		drawRoundedRect(1,1,126,126,8,clearPixel);
		  		// 12 line
		  		drawLine(63,3,63,14,clearPixel);
		  		drawLine(64,3,64,14,clearPixel);
		  		// 6 line
		  		drawLine(63,113,63,124,clearPixel);
		  		drawLine(64,113,64,124,clearPixel);
		  		// 9 line
		  		drawLine(3,63,14,63,clearPixel);
		  		drawLine(3,64,14,64,clearPixel);
		  		// 3 line
		  		drawLine(113,63,124,63,clearPixel);
		  		drawLine(113,64,124,64,clearPixel);
		  		// 1 line
		  		drawLine(92,13,99,3,clearPixel);
		  		drawLine(92,14,98,3,clearPixel);
		  		// 2 line
		  		drawLine(113,35,124,29,clearPixel);
		  		drawLine(114,35,124,30,clearPixel);
		  		// 5 line
		  		drawLine(92,114,99,124,clearPixel);
		  		drawLine(92,113,98,124,clearPixel);
		  		// 4 line
		  		drawLine(113,92,124,98,clearPixel);
		  		drawLine(114,93,124,99,clearPixel);
		  		// 11 line
		  		drawLine(35,14,29,3,clearPixel);
		  		drawLine(35,13,28,3,clearPixel);
		  		// 10 line
		  		drawLine(14,34,3,29,clearPixel);
		  		drawLine(14,35,3,28,clearPixel);
		  		// 8 line
		  		drawLine(14,92,3,99,clearPixel);
		  		drawLine(14,93,3,98,clearPixel);
		  		// 7 line
		  		drawLine(34,113,29,124,clearPixel);
		  		drawLine(35,113,28,124,clearPixel);

		  		// hour hand
		  		int16_t angle_hour = hours*360/12 + (minutes/2) - 90;
		  		drawLine(64,64,64+35*i16_cos(angle_hour)/32768,64+35*i16_sin(angle_hour)/32768,clearPixel);

		  		// minute hand
		  		int16_t angle_minute = minutes*360/60 - 90;
		  		drawLine(64,64,64+46*i16_cos(angle_minute)/32768,64+52*i16_sin(angle_minute)/32768,clearPixel);

		  		// second hand
		  		/*
		  		int16_t angle_second = seconds * 360 / 60 - 90;
		  		drawLine(64,64,64+62*i16_cos(angle_second)/32768, 64+62*i16_sin(angle_second)/32768,clearPixel);*/


		  		// Send frame
		  		HAL_GPIO_WritePin(LCD_SCS_GPIO_Port, LCD_SCS_Pin, GPIO_PIN_SET);

		  		HAL_SPI_Transmit(&hspi1, (uint8_t*)command, 1, HAL_MAX_DELAY);
		  		//HAL_SPI_Transmit(&hspi1, data, SCREEN_HEIGHT * ((SCREEN_WIDTH >> 3) + 2), HAL_MAX_DELAY);
		  		HAL_SPI_Transmit_DMA(&hspi1, data, SCREEN_HEIGHT * ((SCREEN_WIDTH >> 3) + 2));
		  		HAL_SPI_Transmit(&hspi1, 0x00, 1, HAL_MAX_DELAY);
}
/* USER CODE END 4 */

/* StartDefaultTask function */
void StartDefaultTask(void const * argument)
{

  /* USER CODE BEGIN 5 */
  /* Infinite loop */
  for(;;)
  {




    osDelay(25);
  }
  /* USER CODE END 5 */ 
}

/**
  * @brief  Period elapsed callback in non blocking mode
  * @note   This function is called  when TIM2 interrupt took place, inside
  * HAL_TIM_IRQHandler(). It makes a direct call to HAL_IncTick() to increment
  * a global variable "uwTick" used as application time base.
  * @param  htim : TIM handle
  * @retval None
  */
void HAL_TIM_PeriodElapsedCallback(TIM_HandleTypeDef *htim)
{
  if (htim->Instance == TIM2) {
    HAL_IncTick();
  }
}

/**
  * @brief  This function is executed in case of error occurrence.
  * @param  None
  * @retval None
  */
void Error_Handler(void)
{
  /* USER CODE BEGIN Error_Handler */
  /* User can add his own implementation to report the HAL error return state */
  while(1) 
  {
  }
  /* USER CODE END Error_Handler */ 
}

#ifdef USE_FULL_ASSERT

/**
   * @brief Reports the name of the source file and the source line number
   * where the assert_param error has occurred.
   * @param file: pointer to the source file name
   * @param line: assert_param error line source number
   * @retval None
   */
void assert_failed(uint8_t* file, uint32_t line)
{
  /* USER CODE BEGIN 6 */
  /* User can add his own implementation to report the file name and line number,
    ex: printf("Wrong parameters value: file %s on line %d\r\n", file, line) */
  /* USER CODE END 6 */

}

#endif

/**
  * @}
  */ 

/**
  * @}
*/ 

/************************ (C) COPYRIGHT STMicroelectronics *****END OF FILE****/

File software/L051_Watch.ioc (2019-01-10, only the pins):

Mcu.UserName=STM32L051K8Tx
PA0.GPIO_Label=PB_TOP
PA0.Signal=GPXTI0
PA1.GPIO_Label=PB_MID
PA1.Signal=GPXTI1
PA13.Signal=SYS_SWDIO
PA14.Signal=SYS_SWCLK
PA2.GPIO_Label=PB_LOW
PA2.Signal=GPXTI2
PA3.GPIO_Label=EXTCOMIN
PA3.Signal=GPIO_Output
PA5.GPIO_Label=LCD_SCLK
PA5.Signal=SPI1_SCK
PA7.GPIO_Label=LCD_SI
PA7.Signal=SPI1_MOSI
PA8.GPIO_Label=LCD_SCS
PA8.Signal=GPIO_Output
PB3.GPIO_Label=LED
PB3.Signal=GPIO_Output
PC14-OSC32_IN.Signal=RCC_OSC32_IN
PC15-OSC32_OUT.Signal=RCC_OSC32_OUT
